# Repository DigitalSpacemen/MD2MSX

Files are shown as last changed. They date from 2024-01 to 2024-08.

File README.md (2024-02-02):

## About MD2MSX

MD2MSX is a joystick adapter to connect a Mega Drive / Genesis controller to an MSX computer. Software that works with the [JoyMega](https://frs.badcoffee.info/hardware/joymega-en.html) adapter should also work with the MD2MSX.

This is a hardware project by retro computing enthusiasts. We are not experts. **USE AT YOUR OWN RISK!** Please make sure to read the [Usage Notes](#important-usage-notes) first.

Photo of MD2MSX externals

### Why another joystick adapter?

The JoyMega works great with official controllers. However, many 3rd-party controllers don't implement the controller protocol very accurately. Here's some examples of possible issues:

- 8BitDo wireless receivers working in 3-/6-button mode, but not working as a plain MSX joystick.
- Retro-Bit wired controllers and receivers not working in 6-button mode.
- Unbranded 3rd party controller switching to a permanent 3-button mode when the Mode button is pressed in-game.

Please check our [Controller Notes](Controller%20Notes.md) for more detailed information.

### How does MD2MSX work?

Our proposed solution places an Arduino inbetween the controller and the MSX. This Arduino robustly reads the controller on the input side. On the output side, it implements the controller protocol more accurately than the 3rd-party controllers. We designed a simple PCB for this purpose with two DB-9 (or DE-9) ports and header pins to plug in an Arduino Nano. MD2MSX also implements the JoyMega pin mapping and select signal inversion. MD2MSX should be connected to the MSX directly; do not connect it to the JoyMega.

Photo of MD2MSX internals
*MD2MSX with a cable soldered directly to the board in place of the 2nd DB-9 port.*

### How do I make one?

Apart from the MD2MSX PCB you need the following components:

- 1x male DB-9 port (matching the footprint on the PCB).
- 1x female DB-9 port (matching the footprint on the PCB) **OR** a cable with a female DB-9 at the end, to solder directly to the board.
- 2x BAT85 DO-35 diodes. Other switching diodes should also work, but have not been tested.
- 2x 15-pin female header pins.
- 1x Arduino Nano (or clone) with male header pins.

For the hardware, the [KiCad](https://www.kicad.org/) design files can be found in the hardware/ directory. KiCad is used to produce Gerber files for upload to your favourite PCB manufacturer.

The firmware resides in firmware/ and is compiled with [PlatformIO](https://platformio.org/).

### Important usage notes

Do not connect the MD2MSX to both an MSX computer and USB at the same time, even if only one of the devices is powered on!

If you're planning to use a wireless receiver, the current draw may exceed the 50mA rating of the MSX joystick port. Make sure your particular MSX computer can handle this.

### Some things to consider if you decide to build one

If you build it without the cable directly attached, you would either need to obtain a straight-through DB-9 to DB-9 cable, or figure out a way to plug the board directly into the MSX computer. The latter may prove to be difficult.

Ensure the cable going to the MSX computer has a sufficient gauge for the current needed by the Arduino and the controller, especially if you're planning to use a wireless receiver. If you do end up using a cable with thin wires, we recommend making the cable as short as possible.

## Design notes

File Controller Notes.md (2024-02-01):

## Notes on specific 6-button Mega Drive / Genesis controllers

These are some quick notes on various controllers we tested.

- Cycle numbers in this document are 0-based.
- Reponse time: the time it takes the controller to update the output pins after the select pin is toggled.
- Reset time: the time the controller remains in cycle 2+ before falling back to cycle 0 or 1.

### SEGA Arcade Power Stick II

Response time: ~65ns

Reset time: ~1.4ms

### Unbranded "16-BIT" controller

Response time: ~125ns

Reset time: ~2.3ms

Deviations:
- Under certain conditions pressing Mode in-game makes it enter 3-button mode, while this should only happen on startup. We haven't gotten to the bottom of this yet.

### Retro-Bit Bluetooth Receiver

Response time: ~200ns

Reset time: ~0.1ms

Deviations:
- Extremely short reset time.

### Retro-Bit Big6

Response time: ~290ns

Reset time: ~0.1ms

Deviations:
- Extremely short reset time.

### 8BitDo Bluetooth Receiver

Reponse time: ~490ns, but only properly handles select toggles that are at least ~1.4µs apart.

Reset time: ~1.6ms

Deviations:
- 3.3V outputs instead of 5V.
- After cycle 7 it repeats all cycles instead of just cycles 0 and 1.
- After a reset with the select pin low (i.e. cycle 1 is entered), a select toggle will then make it enter cycle 0 instead of cycle 2.
- Buttons are latched on select toggle and are not updated otherwise.
- One additional button: Home (in cycle 7).

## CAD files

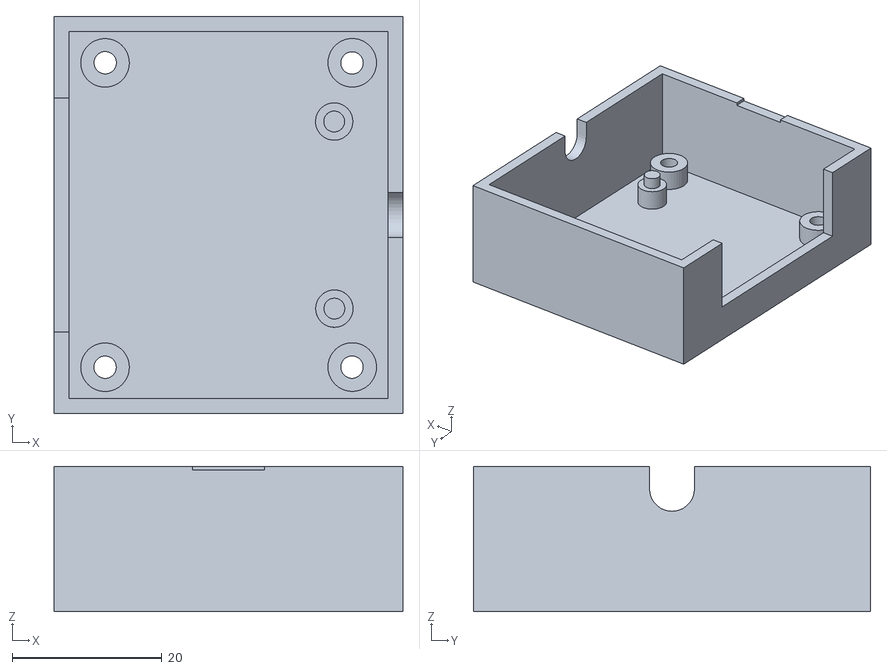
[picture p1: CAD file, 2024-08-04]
case/MS2MSX Bottom Case.stl
46.6 x 53.1 x 19.4

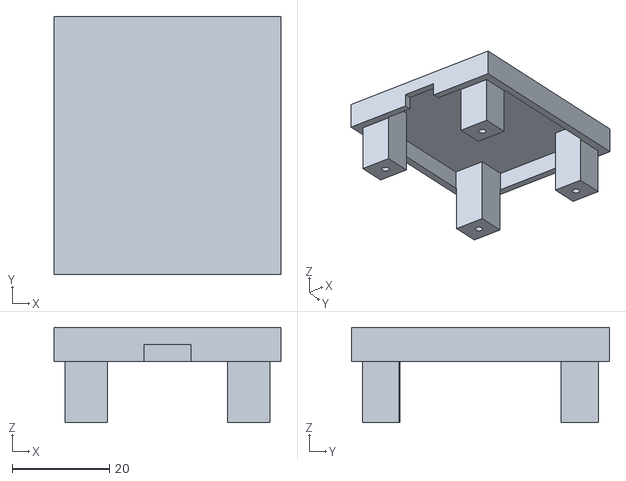
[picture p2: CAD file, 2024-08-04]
case/MD2MSX Top Case.stl
46.6 x 53.1 x 19.6

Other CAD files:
case/MD2MSX v70.f3d

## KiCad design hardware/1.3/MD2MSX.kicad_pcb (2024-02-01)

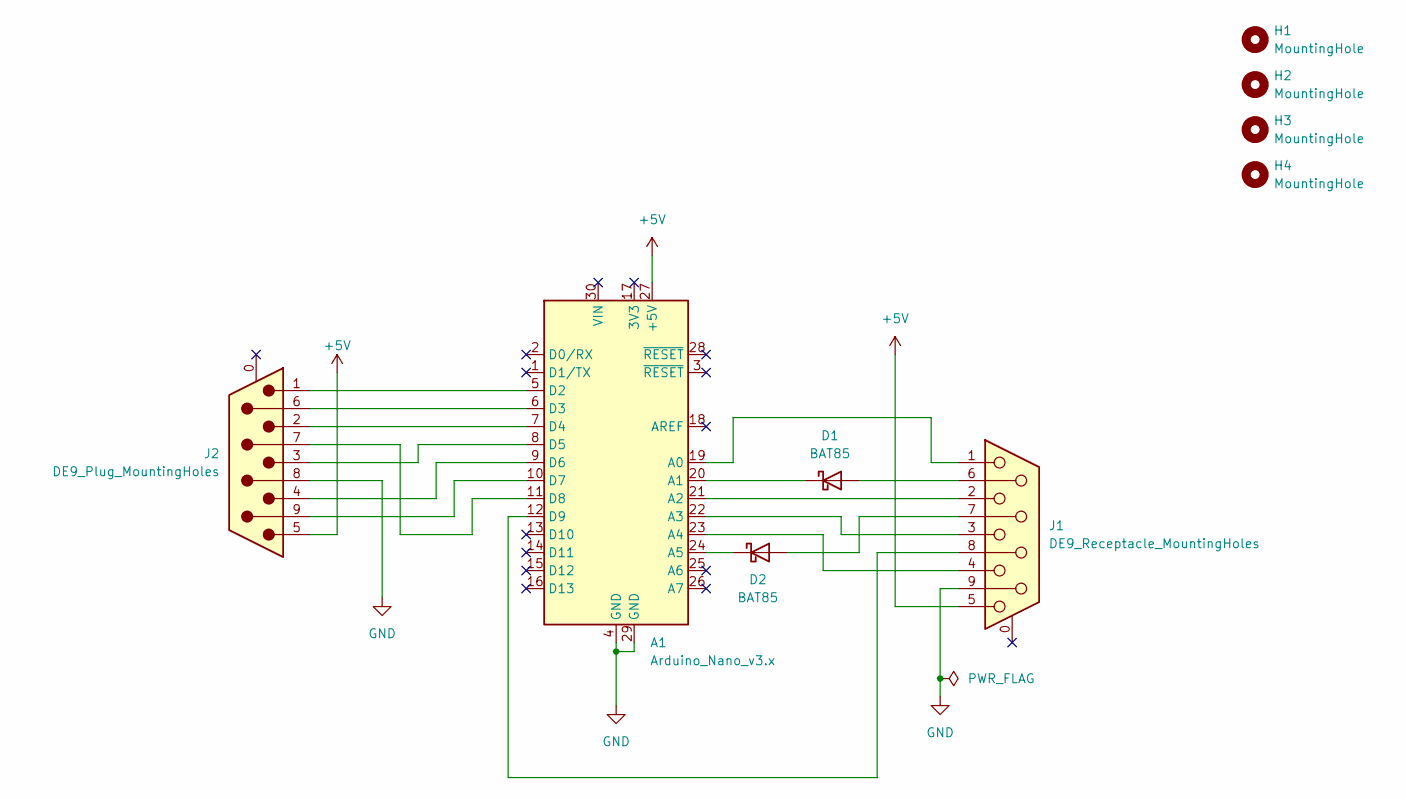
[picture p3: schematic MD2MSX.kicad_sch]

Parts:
A1: Arduino_Nano_v3.x; Arduino_Nano
D1, D2: BAT85; D_DO-35_SOD27_P7.62mm_Horizontal
H1, H2, H3, H4: MountingHole; MountingHole_3.2mm_M3
J1: DE9_Receptacle_MountingHoles; DSUB-9_Female_Horizontal_P2.77x2.84mm_EdgePinOffset9.90mm_H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
J2: DE9_Plug_MountingHoles; DSUB-9_Male_Horizontal_P2.77x2.84mm_EdgePinOffset9.90mm_Hou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

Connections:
+5V: A1.27 (+5V), J1.5, J2.5
GND: A1.4 (GND), A1.29 (GND), J1.9, J2.8
unnamed: A1.19 (A0), J1.1
unnamed: A1.20 (A1), D1.1 (K)
unnamed: A1.21 (A2), J1.2
unnamed: A1.22 (A3), J1.3
unnamed: A1.23 (A4), J1.4
unnamed: A1.24 (A5), D2.1 (K)
unnamed: A1.5 (D2), J2.1
unnamed: A1.6 (D3), J2.6
unnamed: A1.7 (D4), J2.2
unnamed: A1.8 (D5), J2.3
unnamed: A1.9 (D6), J2.4
unnamed: A1.10 (D7), J2.9
unnamed: A1.11 (D8), J2.7
unnamed: A1.12 (D9), J1.8
unnamed: D1.2 (A), J1.6
unnamed: D2.2 (A), J1.7

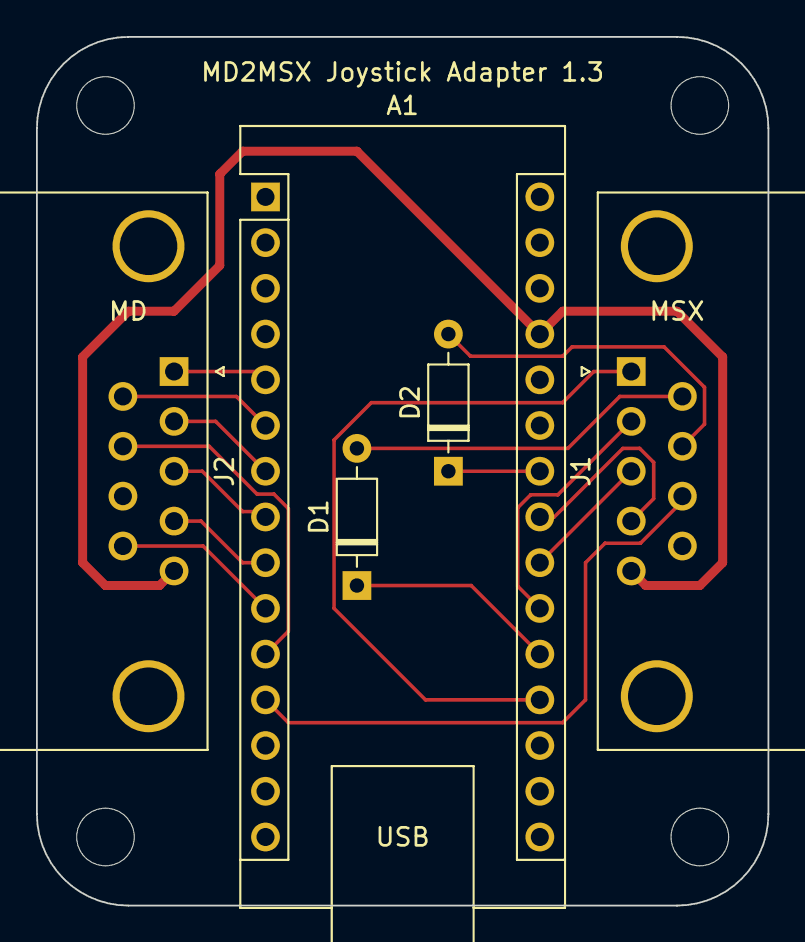
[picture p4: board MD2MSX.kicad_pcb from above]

Board: 2 copper layers, 40.6 x 48.3 mm, 9 parts (0 on the bottom side), 18 nets.

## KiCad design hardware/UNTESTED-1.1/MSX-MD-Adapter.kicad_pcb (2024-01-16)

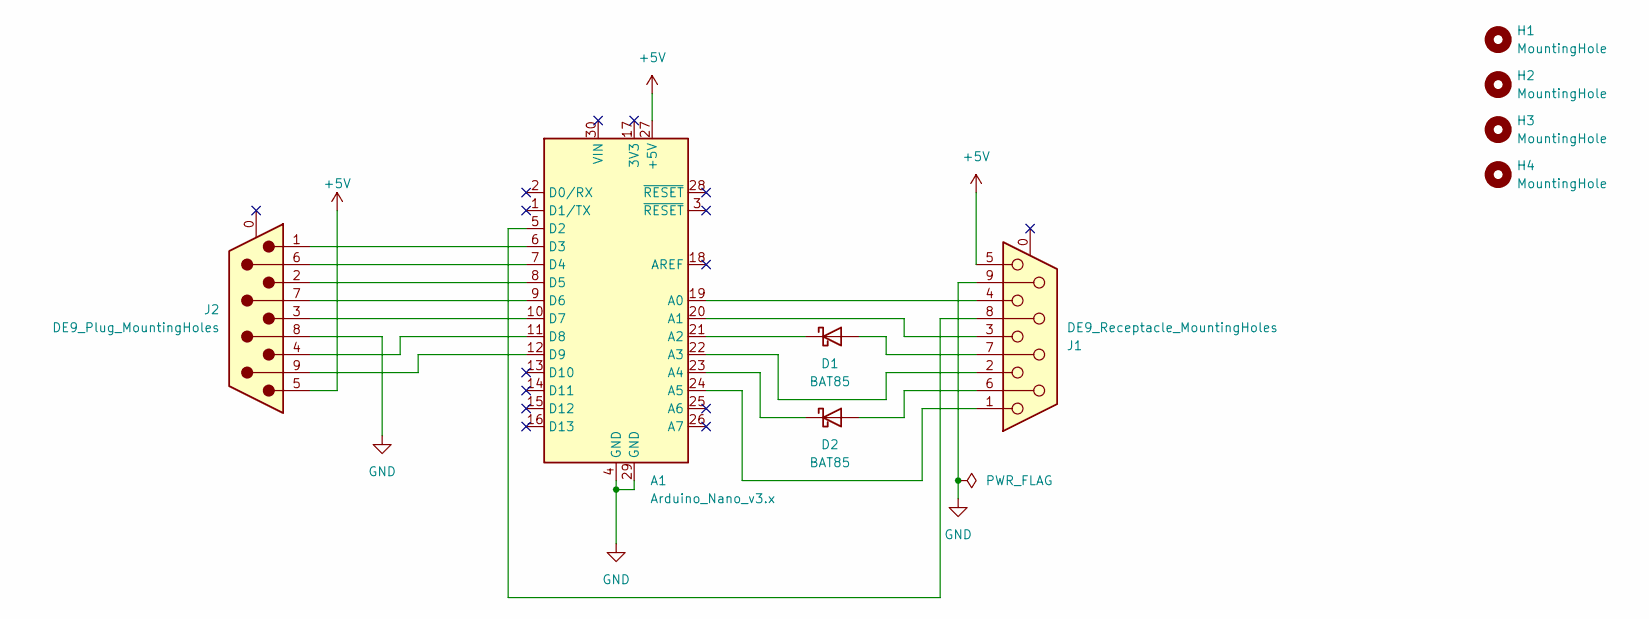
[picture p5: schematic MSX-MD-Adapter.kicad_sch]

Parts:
A1: Arduino_Nano_v3.x; Arduino_Nano
D1, D2: BAT85; D_DO-35_SOD27_P7.62mm_Horizontal
H1, H2, H3, H4: MountingHole; MountingHole_3.2mm_M3
J1: DE9_Receptacle_MountingHoles; DSUB-9_Female_Horizontal_P2.77x2.84mm_EdgePinOffset9.90mm_H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
J2: DE9_Plug_MountingHoles; DSUB-9_Male_Horizontal_P2.77x2.84mm_EdgePinOffset9.90mm_Hou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

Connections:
+5V: A1.27 (+5V), J1.5, J2.5
GND: A1.4 (GND), A1.29 (GND), J1.9, J2.8
unnamed: A1.19 (A0), J1.4
unnamed: A1.20 (A1), J1.3
unnamed: A1.21 (A2), D1.1 (K)
unnamed: A1.22 (A3), J1.2
unnamed: A1.23 (A4), D2.1 (K)
unnamed: A1.24 (A5), J1.1
unnamed: A1.5 (D2), J1.8
unnamed: A1.6 (D3), J2.1
unnamed: A1.7 (D4), J2.6
unnamed: A1.8 (D5), J2.2
unnamed: A1.9 (D6), J2.7
unnamed: A1.10 (D7), J2.3
unnamed: A1.11 (D8), J2.4
unnamed: A1.12 (D9), J2.9
unnamed: D1.2 (A), J1.7
unnamed: D2.2 (A), J1.6

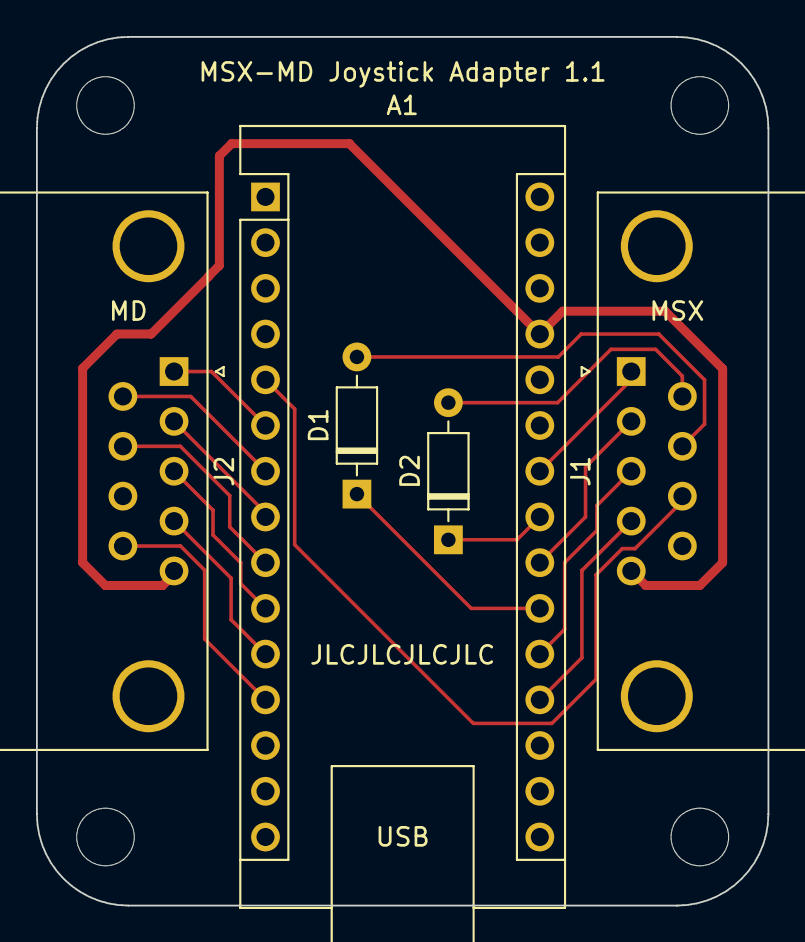
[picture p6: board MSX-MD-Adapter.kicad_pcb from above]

Board: 2 copper layers, 40.6 x 48.3 mm, 9 parts (0 on the bottom side), 18 nets.

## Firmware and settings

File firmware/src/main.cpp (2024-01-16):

/* Copyright (C) 2024  Walter van Niftrik, Kris McAulay
 *
 * This file is part of MD2MSX.
 * 
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
 * You should have received a copy of the GNU General Public License along
 * with MD2MSX. If not, see <https://www.gnu.org/licenses/>.
 */

#include <Arduino.h>
#include "controller.h"

static Controller gController;

void setup() {
#ifdef DEBUG
	Serial.begin(9600);
#else
	noInterrupts();
#endif

	gController.init();
}

void loop() {
#ifdef DEBUG
	gController.debug();
#else
	gController.go();
#endif
}

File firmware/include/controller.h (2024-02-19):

/* Copyright (C) 2024  Walter van Niftrik, Kris McAulay
 *
 * This file is part of MD2MSX.
 * 
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
 * You should have received a copy of the GNU General Public License along
 * with MD2MSX. If not, see <https://www.gnu.org/licenses/>.
 */

#include <Arduino.h>
#include "delay.h"
#include "pin.h"

#ifndef CONTROLLER_H
#define CONTROLLER_H

class Controller {
public:
	Controller();
	void init() const;
	void go();
	void debug();

private:
	enum Type {
		None, ThreeButton, SixButton
	};

	enum Button {
		Up, Down, Left, Right, A, B, C, Start,
		X, Y, Z, Mode,
		Home, // 8BitDo-only
		Count
	};

	void resetMSXTimer() const;
	bool isMSXTimerDone() const;
	void resetControllerTimer() const;
	bool isControllerTimerDone() const;
	void readControllerButtons();
	void writeMSXButtons(uint8_t cycleNr) const;
	bool hasMSXCycleChanged(uint8_t cycleNr) const;
	// This "inline" is essential for speeding up the code
	inline bool handleMSXCycle(uint8_t cycleNr);

	// Debug functions
	Type getControllerType() const;
	void printState() const;
	bool getButton(Button button) const;
	void printButton(Button button, const char *name) const;

	static constexpr int kCycles = 8;

	// Maps controller pin to Arduino pin
	static constexpr uint8_t mapControllerPin(uint8_t cPin) {
		// PCB version 1.3
		constexpr uint8_t pinMap[] = { 0, 2, 4, 5, 6, 0, 3, 8, 0, 7 };
		return pinMap[cPin];
	};

	// Maps MSX pin to Arduino pin
	static constexpr uint8_t mapMSXPin(uint8_t mPin) {
		// PCB version 1.3
		constexpr uint8_t pinMap[] = { 0, 14, 16, 17, 18, 0, 15, 19, 9, 0 };
		return pinMap[mPin];
	};

	// Bitmask for a single button in a cycle
	static constexpr uint8_t buttonBit(Button b) {
		// Maps button to DE-9 input pin
		constexpr uint8_t buttonToPin[Button::Count] = {
			1, 2, 3, 4, 6, 6, 9, 9,
			3, 2, 1, 4,
			1
		};

		// Pins are right-shifted two bits in _cycles
		return bit(mapControllerPin(buttonToPin[b]) - 2);
	};

	// Bitmask for all buttons in a cycle
	static constexpr uint8_t buttonMask() {
		uint8_t mask = 0;

		for (uint8_t b = 0; b < Button::Count; ++b)
			mask |= buttonBit(static_cast<Button>(b));

		return mask;
	};

	// Cache for cycles read from the controller
	uint8_t _cycles[kCycles];
	// Next cycle to read
	uint8_t _controllerCycle;
};

bool Controller::getButton(Controller::Button button) const {
	// Maps button to input read cycle
	constexpr uint8_t buttonCycle[Button::Count] = {
		0, 0, 0, 0, 3, 0, 0, 3,
		6, 6, 6, 6,
		7
	};

	return _cycles[buttonCycle[button]] & buttonBit(button);
}

Controller::Controller() :
		_controllerCycle(0) {
	// Enable pull-ups
	pinSet(mapControllerPin(1));
	pinSet(mapControllerPin(2));
	pinSet(mapControllerPin(3));
	pinSet(mapControllerPin(4));
	pinSet(mapControllerPin(6));
	pinSet(mapControllerPin(9));

	// Configure the controller cycle output pin (default high)
	pinSet(mapControllerPin(7));
	pinModeOutput(mapControllerPin(7));

	// Configure the output pins to the MSX (default high)
	pinSet(mapMSXPin(1));
	pinModeOutput(mapMSXPin(1));
	pinSet(mapMSXPin(2));
	pinModeOutput(mapMSXPin(2));
	pinSet(mapMSXPin(3));
	pinModeOutput(mapMSXPin(3));
	pinSet(mapMSXPin(4));
	pinModeOutput(mapMSXPin(4));
	pinSet(mapMSXPin(6));
	pinModeOutput(mapMSXPin(6));
	pinSet(mapMSXPin(7));
	pinModeOutput(mapMSXPin(7));

	// Enable pull-up for MSX cycle pin
	pinSet(mapMSXPin(8));

	for (uint8_t &c : _cycles)
		c = UINT8_MAX;
};

void Controller::init() const {
	// Initialize Timer1
	TCCR1A = 0;
	TCCR1B = 0;
	TCNT1 = 0;

	// Disable all Timer1 interrupts
	TIMSK1 = 0;

	// Reset Timer1 compare A flags
	TIFR1 |= _BV(OCF1A);

	// Set Timer1 compare A to 1.5ms
	OCR1A = 15 * F_CPU / 10000;

	// Start Timer1 without prescaling
	TCCR1B = _BV(CS10);

	// Initialize Timer2
	TCCR2A = 0;
	TCCR2B = 0;
	TCNT2 = 0;

	// Disable all Timer2 interrupts
	TIMSK2 = 0;

	// Reset Timer2 flags
	TIFR2 |= _BV(OCF2A);

	// Set Timer2 compare A to 3ms
	OCR2A = 3 * F_CPU / 1000 / 256;

	// Start Timer2 with 256 prescaling
	TCCR2B = _BV(CS22) | _BV(CS21);
}

void Controller::readControllerButtons() {
	// PIND / 4 generates faster code here, if we need it
	_cycles[_controllerCycle] = PIND >> 2;
	_controllerCycle = (_controllerCycle + 1) & 7;
	pinToggle(mapControllerPin(7));
}

void Controller::writeMSXButtons(uint8_t cycleNr) const {
	PORTC = _cycles[cycleNr];
}

bool Controller::hasMSXCycleChanged(uint8_t cycleNr) const {
	return (cycleNr & 1) != pinRead(mapMSXPin(8));
}

bool Controller::handleMSXCycle(uint8_t cycleNr) {
	while (!hasMSXCycleChanged(cycleNr)) {
		// writeMSXButtons() currently also functions as the delay for
		// readControllerButtons(). For PCB 1.2 the code is close to the
		// speed of the 8BitDo receiver. If the code ever becomes faster,
		// an additional delay mechanism will need to be added in order
		// to maintain 8BitDo compatibility. 8BitDo breaks at around a 1.5us
		// delay between toggles.
		writeMSXButtons(cycleNr & 7);

		if (_controllerCycle == 0) {
			while (!isControllerTimerDone()) {
				if (hasMSXCycleChanged(cycleNr))
					return false;
				if (cycleNr >= 2 && isMSXTimerDone())
					return true;
			}
			resetControllerTimer();
		}

		if (hasMSXCycleChanged(cycleNr))
			return false;

		readControllerButtons();
	}

	return false;
}

void Controller::resetMSXTimer() const {
	// Set timer to 0
	TCNT1 = 0;
	// Clear compare A flag
	TIFR1 |= bit(OCF1A);
}

bool Controller::isMSXTimerDone() const {
	// Check compare A flag
	return TIFR1 & _BV(OCF1A);
}

void Controller::resetControllerTimer() const {
	// Set timer to 0
	TCNT2 = 0;
	// Clear compare A flag
	TIFR2 |= bit(OCF1A);
}

bool Controller::isControllerTimerDone() const {
	// Check compare A flag
	return TIFR2 & _BV(OCF2A);
}

void Controller::go() {
#ifdef DEBUG
	printState();
#endif

	handleMSXCycle(0);
	handleMSXCycle(1);

	// Restart the timer
	resetMSXTimer();

	if (handleMSXCycle(2))
		return;

	if (handleMSXCycle(3))
		return;

	if (handleMSXCycle(4))
		return;

	if (handleMSXCycle(5))
		return;

	if (handleMSXCycle(6))
		return;

	if (handleMSXCycle(7))
		return;

	for (;;) {
		if (handleMSXCycle(8))
			return;

		if (handleMSXCycle(9))
			return;
	}
}

Controller::Type Controller::getControllerType() const {
	if ((_cycles[7] & buttonBit(Button::Left)) && (_cycles[7] & buttonBit(Button::Right))) {
		if (!(_cycles[5] & buttonBit(Button::Left)) && !(_cycles[5] & buttonBit(Button::Right)))
			return SixButton;
		else
			return None;
	}

	return ThreeButton;
}

void Controller::printButton(Button button, const char *name) const {
	if (!getButton(button)) {
		Serial.print(name);
		Serial.print(' ');
	}
}
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

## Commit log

2024-01-17 Replace DEBUG #define with constexpr
    [controller.h, main.cpp]
2024-01-18 Add firmware for PCB 1.2
    [MD2MSX.kicad_pcb, MD2MSX.kicad_sch, MSX-MD-Adapter.kicad_pcb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]
2024-01-23 Custom pin code
2024-02-01 PCB version 1.3
    [MD2MSX.kicad_pcb, MD2MSX.kicad_sch]
2024-02-01 Rename directories
    [MD2MSX.kicad_pcb, MD2MSX.kicad_sch, MSX-MD-Adapter.kicad_pcb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]
2024-02-01 Remove old board versions
    [MD2MSX.kicad_pcb, MD2MSX.kicad_sch, MSX-MD-Adapter.kicad_pcb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]
2024-08-04 Add case
    [MD2MSX Top Case.stl, MD2MSX v70.f3d, MS2MSX Bottom Case.stl]

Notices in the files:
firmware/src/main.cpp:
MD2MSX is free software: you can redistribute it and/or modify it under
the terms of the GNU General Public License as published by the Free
